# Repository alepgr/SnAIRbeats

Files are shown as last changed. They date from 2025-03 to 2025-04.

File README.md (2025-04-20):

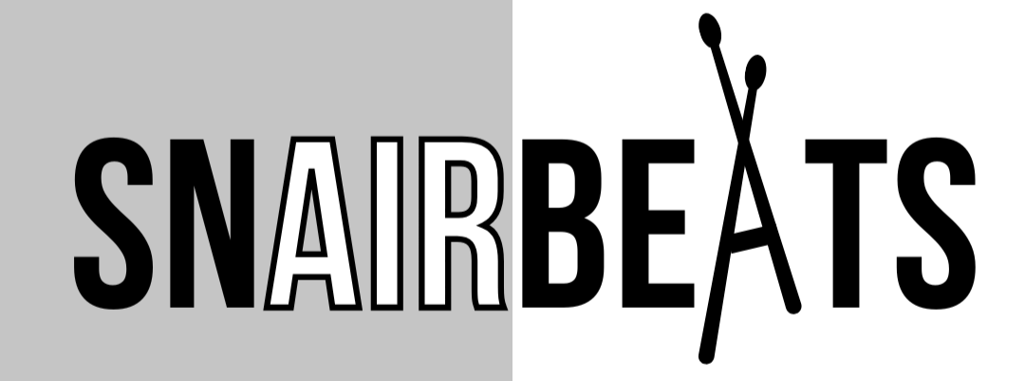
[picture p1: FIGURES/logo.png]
Snairbeats logo


# SnAIRbeats
SnAirBeats is a next generation method to practice the drums, while reducing noise and space typically required to do so. The SnAirBeat set uses intertial measurement units (IMU) within the sticks to track their movement and play a corresponding drum, not requiring any physical hitting like modern electric drum sets need.

# Building
SnAIRBeats requires the following components to work:

* 1x  [Raspberry Pi 5](https://uk.rs-online.com/web/p/raspberry-pi/0219255)
* 2x  [SEN15335 Breakout IMU](https://uk.rs-online.com/web/p/sensor-development-tools/2836590)
* 1x  [External USB Speaker](https://thepihut.com/products/mini-external-usb-stereo-speaker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)

The circuit's wires should be at least 1m long to ensure comfortable movement while playing to avoid risk of damaging the project.
A wiring guide can be seen below:

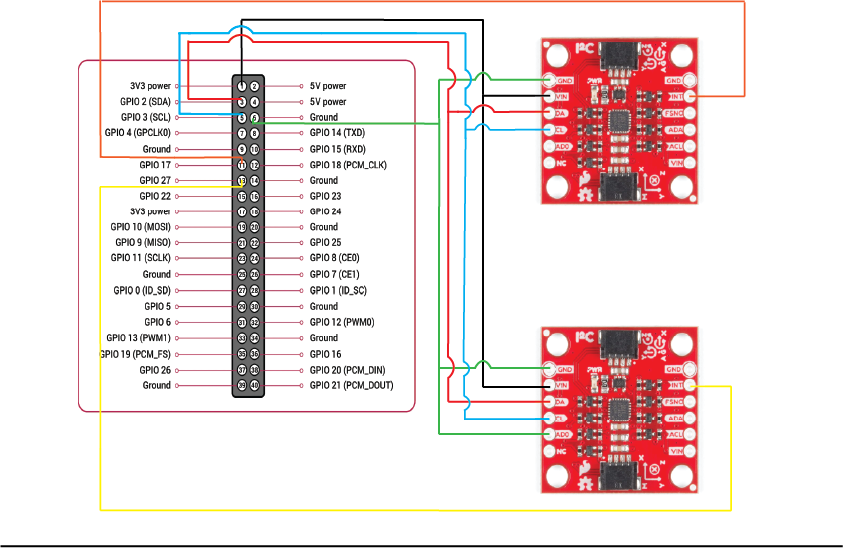
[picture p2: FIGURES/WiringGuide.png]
Wiring guide


The drumsticks for the project need to be 3D printed via the [STLs](/STLs/) provided within this repository.

# Prerequisites
Firstly it should be noted that SnAIRBeats can only run on a Linux system. It is recommened to use a Raspberry Pi operating system such as [Raspebian](https://www.raspberrypi.com/software/) as the packages will not work on Windows systems.  

Before installing any of the prerequisites, please update your package list with:
```
sudo apt update
```

There are 4 main libraries that need to be installed for this project:
* Libgpiod - for general purpose input/output
* mraa - IoT and hardware interface library (required for IMU driver)
* YAML - Support for YAML (required for IMU driver)
* ALSA - To process and play sound files

These packages can be installed by running the following commands through the terminal of the Raspberry Pi.
```
sudo apt install -y libgpiod-dev
sudo apt install -y libmraa-dev
sudo apt install -y libyaml-dev
sudo apt install -y libasound2-dev
```

# Compliation from source

The project is built using a series of CMakeLists.txt which locate and link the required internal and external libraries for the project. By running the code below, the CMake will generate the respective make files within each of files. Running make will build the project and return an executable.

```
cmake .
make
```

It may take a few seconds for everything to build properly, but once everything has been successfully created you can use the code below to run SnAIRBeats.  

```
./SnairBeats
```

# Usage
SnAIRBeats works by reading the direction of acceleration within the IMUs. Holding the sticks with the X-direction representing the vertical axis:
* Hitting a stick down will play a snare drum
* Hitting a stick to either side will play a high tom
* Lunging the stick forward will play a crash cymbal

If desired, the sounds played by each direction can be changed by swapping files in the ALSAPlayer library found either [here](src/libs/ALSAPlayer/include) or through the command directory:
```
cd src/libs/ALSAPlayer/include
ls
```

## Maximum Latency
The highest sampling rate the SEN 15335 IMUs can work at is 1.125kHz.  
This value can be adjusted in the main.cpp file by altering the SampleRateDivider variable. This divides the sampling rate by 1+SampleRateDivider.  

We have found that the maximum latency the sticks can be reliably played at is 25Hz (1125Hz/44+1). While decreasing the latency may improve the sensitivity of the sticks, the higher this value is the greater the power consumption will be.

# Libraries
Here is a small description of each of the libraries used within the project and what they are used for.

## ALSAPlayer
ALSAPlayer takes .wav files from inside its [include folder](src/libs/ALSAPlayer/include/) and converts them into audio buffers using the ConvertFiles function. This library is heavily based off of driver written by [Adam Stark](https://github.com/adamstark) found at [https://github.com/adamstark/AudioFile](https://github.com/adamstark/AudioFile).

Audio devices are opened using the Open function which once finished can be used to play the created audiobuffers using the playFile function. The playFile function is built to play small audios and will interrupt itself, cancelling whatever is playing to play the next audio. This is much easier for SnAIRBeats compared to mixing as the interrupt of the drum notes is not noticable to the human ear, especially with the sample delay between each hit.

## GPIO
The GPIO library initialises the GPIO pins of the Raspberry Pi. Using [libgpiod](https://libgpiod.readthedocs.io/en/latest/), an event driven interrupt function called "worker" is used to read one of the GPIO pins for a HIGH value. The function is blocked until a rising edge event is seen in the GPIO pin selected in the constructor.  

The interrupt is data-ready based and therefore wakes whenever new data is available from the sensor. Within the constructor, 2 objects were passed in, the Maths object and the I2C-IMU driver. The new data is read from the IMU's registers using a read function and passed into a callback which inputs the data into the maths object to be thresholded.

## I2C
The I2C library is a driver written specifically for the [ICM-20948 chip](https://invensense.tdk.com/wp-content/uploads/2016/06/DS-000189-ICM-20948-v1.3.pdf) seen within the SEN 15335 IMU and is very heavily based off of driver written by [NTKot](https://github.com/NTkot) found at [https://github.com/NTkot/icm20948_i2c](https://github.com/NTkot/icm20948_i2c) with the Raw-Data-Ready interrupt turned on and the magnetometer turned off.

For each sensor used within the system, an object from this driver is built with a separate I2C address to differentiate between the two. These objects come with pre-built functions, must useful is the Read_Accel_Gyro which reads the registers of the IMU and stores the values in a variable within the object. These variables are what are passed into the IMUMaths callback through the GPIO worker whenever data is ready.

## IMUMaths
This libary was written to threshold the data that came through from the GPIO worker and has two main goals. Firstly it reads the data passed through and checks whether any of the values correlate to a hit and then play the corresponding audio from the ALSAAudio object. It also contains a sample delay to stop multiple sounds being played from the same hit. This is achieved using a simple boolean that is turned true after a hit is detected and waits a set number of samples before the boolean flips back, allowing another hit to be detected.

# Unit tests
This project uses unit testing to validate the functionality of the key classes, including classes responsible for IMU data processing and audio playback.

Tests are written using the GoogleTest framework and integrated with CTest for easy execution.

To run the tests from the root directory, use:
```
./run_tests
```
or to use CMake directly, run:
```
ctest
```

# Documentation
Complete documentation for this project can be found in [documentation.pdf](./documentation.pdf).

# Sponsorship and funding
We are extremely grateful for RS Components for providing us with components that allowed us to complete this project. We are also very grateful to the ENG5220 Real Time Embedded Programming lecturers and teaching assistants for their guidance throughout the past three months.

# Media
* [Instagram](https://www.instagram.com/snairbeats/)

# Authors
* Calum Robertson
* Aleksandar Zahariev
* Mohammed Alqabandi
* Renata Cia Sanches Loberto
* Alejandra Paja Garcia

# Licenses
The IMU driver has been adapted from the driver written by [NTKot](https://github.com/NTkot) and can be found at [https://github.com/NTkot/icm20948_i2c](https://github.com/NTkot/icm20948_i2c)

The ALSAPlayer library has been adapted from the driver written by [Adam Stark](https://github.com/adamstark) and can be found at [https://github.com/adamstark/AudioFile](https://github.com/adamstark/AudioFile)

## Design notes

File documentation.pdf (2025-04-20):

## SnAirBeats

1.0

Generated by Doxygen 1.13.2

i

1 SnAirBeats | 1
2 Namespace Index | 5
3 Hierarchical Index | 7
4 Class Index | 9
5 File Index | 11
6 Namespace Documentation | 13
7 Class Documentation | 15

Generated by Doxygen

ii

iii

iv

8 File Documentation | 43

# Chapter 1

# SnAirBeats

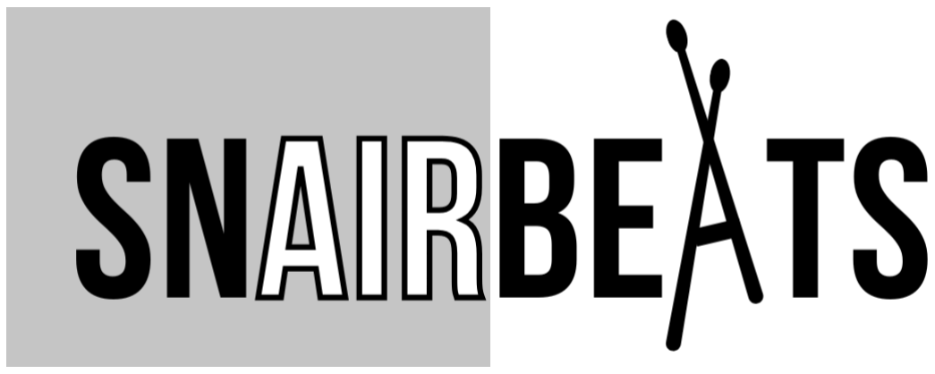
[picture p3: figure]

## 1.1 SnAIRbeats

SnAirBeats is a next generation method to practice the drums, while reducing noise and space typically required to do so. The SnAirBeat set uses intertial measurement units (IMU) within the sticks to track their movement and play a corresponding drum, not requiring any physical hitting like modern electric drum sets need.

## 1.2 Building

SnAIRBeats requires the following components to work:

- 1x Raspberry Pi 5 (https://uk.rs-online.com/web/p/raspberry-pi/0219255)
- 2x SEN15335 Breakout IMU (https://uk.rs-online.com/web/p/sensor-development-tools/2836590)
- 1x External USB Speaker (https://thepihut.com/products/mini-external-usb-stereo-speaker?variant=31955934801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)

The circuit's wires should be at least 1m long to ensure comfortable movement while playing to avoid risk of dam-aging the project. A wiring guide can be seen below:

### 2 SnAirBeats

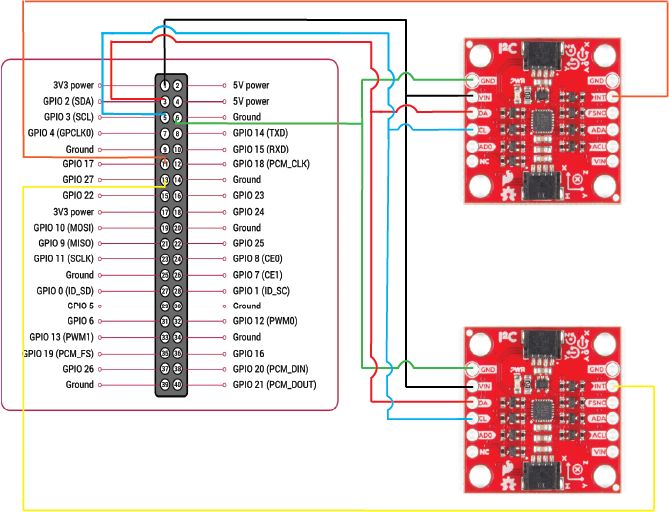
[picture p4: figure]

The drumsticks for the project need to be 3D printed via the STLs provided within this repository.

## 1.3 Prerequisites

Firstly it should be noted that SnAIRBeats can only run on a Linux system. It is recommened to use a Raspberry Pi operating system such as Raspebian (https://www.raspberrypi.com/software/) as the packages will not work on Windows systems.

Before installing any of the prerequisites, please update your package list with:

sudo apt update

There are 4 main libraries that need to be installed for this project:

- Libgpiod - for general purpose input/output
- mraa - IoT and hardware interface library (required for IMU driver)
- YAML - Support for YAML (required for IMU driver)
- ALSA - To process and play sound files

These packages can be installed by running the following commands through the terminal of the Raspberry Pi.

sudo apt install -y libgpiod-dev
sudo apt install -y libmraa-dev
sudo apt install -y libyaml-dev sudo apt install -y libasound2-dev

## 1.4 Compliation from source

The project is built using a series of CMakeLists.txt which locate and link the required internal and external libraries for the project. By running the code below, the CMake will generate the respective make files within each of files. Running make will build the project and return an executable.

cmake .
make

It may take a few seconds for everything to build properly, but once everything has been successfully created you can use the code below to run SnAIRBeats.

./SnairBeats

1.5 Usage | 3

## 1.5 Usage

SnAIRBeats works by reading the direction of acceleration within the IMUs. Holding the sticks with the X-direction representing the vertical axis:

- Hitting a stick down will play a snare drum
- Hitting a stick to either side will play a high tom
- Lunging the stick forward will play a crash cymbal

If desired, the sounds played by each direction can be changed by swapping files in the ALSAPlayer library found either here or through the command directory:

cd src/libs/ALSAPlayer/include
ls

### 1.5.1 Maximum Latency

The highest sampling rate the SEN 15335 IMUs can work at is 1.125kHz.
This value can be adjusted in the main.cpp file by altering the SampleRateDivider variable. This divides the sampling rate by 1+SampleRateDivider.

We have found that the maximum latency the sticks can be reliably played at is 25Hz (1125Hz/44+1). While decreas-ing the latency may improve the sensitivity of the sticks, the higher this value is the greater the power consumption will be.

## 1.6 Libraries

Here is a small description of each of the libraries used within the project and what they are used for.

### 1.6.1 ALSAPlayer

ALSAPlayer takes .wav files from inside its include folder and converts them into audio buffers using the ConvertFiles function. This library is heavily based off of driver written by Adam Stark (https://github.com/adamstark) found at https←-://github.com/adamstark/AudioFile.

Audio devices are opened using the Open function which once finished can be used to play the created audiobuffers using the playFile function. The playFile function is built to play small audios and will interrupt itself, cancelling whatever is playing to play the next audio. This is much easier for SnAIRBeats compared to mixing as the interrupt of the drum notes is not noticable to the human ear, especially with the sample delay between each hit.

### 1.6.2 GPIO

The GPIO library initialises the GPIO pins of the Raspberry Pi. Using libgpiod, (https://libgpiod.readthedocs.io/en/latest/) an event driven interrupt function called "worker" is used to read one of the GPIO pins for a HIGH value. The function is blocked until a rising edge event is seen in the GPIO pin selected in the constructor.

The interrupt is data-ready based and therefore wakes whenever new data is available from the sensor. Within the constructor, 2 objects were passed in, the Maths object and the I2C-IMU driver. The new data is read from the IMU's registers using a read function and passed into a callback which inputs the data into the maths object to be thresholded.

### 4 SnAirBeats

### 1.6.3 I2C

The I2C library is a driver written specifically for the ICM-20948 chip (https://invensense.tdk.com/wp-content/uploads/2016/06/DS-000189-ICM-20948-v1.3.pdf) seen within the SEN 15335 IMU and is very heavily based off of driver written by NTKot found at https://github.com/NTkot/icm20948←-_i2c (https://github.com/NTkot/icm20948_i2c) with the Raw-Data-Ready interrupt turned on and the magnetometer turned off.

For each sensor used within the system, an object from this driver is built with a separate I2C address to differentiate between the two. These objects come with pre-built functions, must useful is the Read_Accel_Gyro which reads the registers of the IMU and stores the values in a variable within the object. These variables are what are passed into the IMUMaths callback through the GPIO worker whenever data is ready.

### 1.6.4 IMUMaths

This libary was written to threshold the data that came through from the GPIO worker and has two main goals. Firstly it reads the data passed through and checks whether any of the values correlate to a hit and then play the corresponding audio from the ALSAAudio object. It also contains a sample delay to stop multiple sounds being played from the same hit. This is achieved using a simple boolean that is turned true after a hit is detected and waits a set number of samples before the boolean flips back, allowing another hit to be detected.

## 1.7 Unit tests

This project uses unit testing to validate the functionality of the key classes, including classes responsible for IMU data processing and audio playback.

Tests are written using the GoogleTest framework and integrated with CTest for easy execution.

To run the tests from the root directory, use:

./run_tests

or to use CMake directly, run:

ctest

## 1.8 Documentation

Complete documentation for this project can be found in documentation.pdf.

## 1.9 Sponsorship and funding

We are very grateful for RS Components for providing us with components that allowed us to complete this project.

## 1.10 Media

- Instagram (https://www.instagram.com/snairbeats/)

1.11 Authors | 5

## 1.11 Authors

- Calum Robertson
- Aleksandar Zahariev
- Mohammed Alqabandi
- Renata Cia Sanches Loberto
- Alejandra Paja Garcia

## 1.12 Licenses

The IMU driver has been adapted from the driver written by NTKot (https://github.com/NTkot) and can be found at https://github.←-com/NTkot/icm20948_i2c (https://github.com/NTkot/icm20948_i2c)

The ALSAPlayer library has been adapted from the driver written by Adam Stark (https://github.com/adamstark) and can be found at https://github.com/adamstark/AudioFile

### 6 SnAirBeats

# Chapter 2

# Namespace Index

## 2.1 Namespace List

Here is a list of all namespaces with brief descriptions:

AudioPlayerName | | 13
GPIOName | | 13
icm20948 | | 13
IMUMathsName | | 13

### 8 Namespace Index

# Chapter 3

# Hierarchical Index

## 3.1 Class Hierarchy

This inheritance list is sorted roughly, but not completely, alphabetically:

AudioPlayerName::AudioPlayer::ActiveSound | | 15
AudioPlayerName::AudioPlayer | | 18
GPIOName::GPIOClass::Callback | | 25
GPIOName::MathsCallbackStruct | 40
IMUMathsName::IMUMaths::Callback | 27
IMUMathsName::AudioCallback | 16
GPIOName::GPIOClass | | 28
icm20948::ICM20948_I2C | | 32
IMUMathsName::IMUMaths | | 38

### 10 Hierarchical Index

# Chapter 4

# Class Index

## 4.1 Class List

Here are the classes, structs, unions and interfaces with brief descriptions:

GPIOName::GPIOClass::Callback

IMUMathsName::IMUMaths::Callback

### 12 Class Index

# Chapter 5

# File Index

## 5.1 File List

Here is a list of all files with brief descriptions:

### 14 File Index

# Chapter 6

# Namespace Documentation

## 6.1 AudioPlayerName Namespace Reference

Classes

- class AudioPlayer

## 6.2 GPIOName Namespace Reference

Classes

- class GPIOClass
- struct MathsCallbackStruct

## 6.3 icm20948 Namespace Reference

Classes

- class ICM20948_I2C

## 6.4 IMUMathsName Namespace Reference

Classes

- struct AudioCallback
- class IMUMaths

### 16 Namespace Documentation

# Chapter 7

# Class Documentation

## 7.1 AudioPlayerName::AudioPlayer::ActiveSound Struct Reference

Collaboration diagram for AudioPlayerName::AudioPlayer::ActiveSound:

### AudioPlayerName::AudioPlayer ::ActiveSound

+ | buffer
+ | position

Public Attributes

- std::vector< int32_t > ∗ buffer
- size_t position

### 7.1.1 Member Data Documentation

### 7.1.1.1 buffer

std::vector<int32_t>∗ AudioPlayerName::AudioPlayer::ActiveSound::buffer

### 7.1.1.2 position

size_t AudioPlayerName::AudioPlayer::ActiveSound::position

The documentation for this struct was generated from the following file:

- src/libs/ALSAPlayer/include/ALSAPlayer.hpp

### 18 Class Documentation

## 7.2 IMUMathsName::AudioCallback Struct Reference

#include <IMUMaths.hpp>

Inheritance diagram for IMUMathsName::AudioCallback:

### IMUMathsName::AudioCallback

+ | Audio
+ | AudioCallback()
+ | AudioTrigger()

### IMUMathsName::IMUMaths ::Callback

+ | AudioTrigger()
+ | ~Callback()

7.2 IMUMathsName::AudioCallback Struct Reference | 19

Collaboration diagram for IMUMathsName::AudioCallback:

### IMUMathsName::AudioCallback

+ | AudioCallback()
+ | AudioTrigger()

### IMUMathsName::IMUMaths ::Callback

+ | AudioTrigger()
+ | ~Callback()

### AudioPlayerName::AudioPlayer

+ | fileBuffers
+ | StopMixingThread

### - deviceName - sampleRate - channels - format

| and 5 more...
+ | AudioPlayer()
+ | open()
+ | startMixer()
+ | stopMixer()
| and 3 more...

### - mixerThreadLoop() - ConvertFiles()

### +Audio

Public Member Functions

- AudioCallback (AudioPlayerName::AudioPlayer &audio)
- virtual void AudioTrigger (const std::string &FilePath)

Public Member Functions inherited from IMUMathsName::IMUMaths::Callback

- virtual ∼Callback ()

Public Attributes

- AudioPlayerName::AudioPlayer & Audio

### 20 Class Documentation

### 7.2.1 Constructor & Destructor Documentation

### 7.2.1.1 AudioCallback()

IMUMathsName::AudioCallback::AudioCallback (

AudioPlayerName::AudioPlayer & audio) [inline]

### 7.2.2 Member Function Documentation

### 7.2.2.1 AudioTrigger()

virtual void IMUMathsName::AudioCallback::AudioTrigger (

const std::string & FilePath) [inline], [virtual]

Implements IMUMathsName::IMUMaths::Callback.

### 7.2.3 Member Data Documentation

### 7.2.3.1 Audio

AudioPlayerName::AudioPlayer& IMUMathsName::AudioCallback::Audio

The documentation for this struct was generated from the following file:

- src/libs/IMUMaths/include/IMUMaths.hpp

## 7.3 AudioPlayerName::AudioPlayer Class Reference

#include <ALSAPlayer.hpp>

7.3 AudioPlayerName::AudioPlayer Class Reference | 21

Collaboration diagram for AudioPlayerName::AudioPlayer:

### AudioPlayerName::AudioPlayer

+ | fileBuffers
+ | StopMixingThread

### - deviceName - sampleRate - channels - format

| and 5 more...
+ | AudioPlayer()
+ | open()
+ | startMixer()
+ | stopMixer()
| and 3 more...

### - mixerThreadLoop() - ConvertFiles()

Classes

- struct ActiveSound

Public Member Functions

- AudioPlayer (const std::string &device="default", unsigned int rate=44100, unsigned int ch=2, snd_pcm_←-format_t fmt=SND_PCM_FORMAT_S16_LE, snd_pcm_uframes_t frames=256, const std::vector< std::string > &filesToConvert={"src/libs/ALSAPlayer/include/CrashCymbal.wav", "src/libs/ALSAPlayer/include/High←-Tom.wav", "src/libs/ALSAPlayer/include/SnareDrum.wav"})

Constructor for AudioPlayer class.
- bool open ()

Open PCM device for playback.
- bool startMixer ()

Start mixer thread.
- void stopMixer ()

Stop mixer thread, closes thread when called.
- bool addSoundToMixer (const std::string &fileKey)

Add input sound to mixer and play it.
- void close ()

Close PCM handle and free all associated resources.
- ∼AudioPlayer ()

Destructor.

### 22 Class Documentation

Public Attributes

- std::unordered_map< std::string, std::vector< int32_t > > fileBuffers
- bool StopMixingThread = false

Private Member Functions

- void mixerThreadLoop ()
- void ConvertFiles (const std::vector< std::string > &filePaths)

Private Attributes

- std::string deviceName
- unsigned int sampleRate
- unsigned int channels
- snd_pcm_format_t format
- snd_pcm_uframes_t framesPerPeriod
- snd_pcm_t ∗ handle
- std::thread mixThread
- std::vector< ActiveSound > ActiveSounds
- std::mutex ActiveMutex

### 7.3.1 Constructor & Destructor Documentation

### 7.3.1.1 AudioPlayer()

AudioPlayerName::AudioPlayer::AudioPlayer (

const std::string & device = "default",

unsigned int rate = 44100,

unsigned int ch = 2,

snd_pcm_format_t fmt = SND_PCM_FORMAT_S16_LE,

snd_pcm_uframes_t frames = 256,

const std::vector< std::string > & filesToConvert = {"src/libs/ALSAPlayer/include/CrashCymbal.wav", "src/libs/ALSAPlayer/include/HighTom.wav", "src/libs/ALSAPlayer/include/SnareDrum.wav"})

[inline]

Constructor for AudioPlayer class.

Handles audio file loading, conversion and playback.

Parameters

device | The name of the ALSA device to use.
rate | Sample rate in Hz.
ch | Number of channels.
fmt | Format of audio data.
frames | Number of frames per period.
filesToConvert | Sound files used.

7.3 AudioPlayerName::AudioPlayer Class Reference | 23

7.3.1.2 ∼AudioPlayer()

AudioPlayerName::AudioPlayer::∼AudioPlayer () [inline]

Destructor.

Here is the call graph for this function:

AudioPlayerName::AudioPlayer ::~AudioPlayer

AudioPlayerName::AudioPlayer ::close

AudioPlayerName::AudioPlayer ::stopMixer

### 7.3.2 Member Function Documentation

### 7.3.2.1 addSoundToMixer()

bool AudioPlayerName::AudioPlayer::addSoundToMixer (

const std::string & fileKey) [inline]

Add input sound to mixer and play it.

It includes the following steps:

- register detected sound in the mixer
- add sound to buffer and remove sounds that have finished playing
- play sound

Parameters

fileKey Sound file key.

Returns

Returns true if sound was added to mixer, false if error

### 24 Class Documentation

### 7.3.2.2 close()

void AudioPlayerName::AudioPlayer::close () [inline]

Close PCM handle and free all associated resources.

Here is the call graph for this function:

AudioPlayerName::AudioPlayer ::close

AudioPlayerName::AudioPlayer ::stopMixer

Here is the caller graph for this function:

AudioPlayerName::AudioPlayer ::close

AudioPlayerName::AudioPlayer ::~AudioPlayer

### 7.3.2.3 ConvertFiles()

void AudioPlayerName::AudioPlayer::ConvertFiles (

const std::vector< std::string > & filePaths) [inline], [private]

### 7.3.2.4 mixerThreadLoop()

void AudioPlayerName::AudioPlayer::mixerThreadLoop () [inline], [private]

Here is the caller graph for this function:

AudioPlayerName::AudioPlayer ::mixerThreadLoop

AudioPlayerName::AudioPlayer
::startMixer | Generated by Doxygen

7.3 AudioPlayerName::AudioPlayer Class Reference | 25

### 7.3.2.5 open()

bool AudioPlayerName::AudioPlayer::open () [inline]

Open PCM device for playback.

It includes the following steps:

- open the PCM device
- allocate hardware parameters object and fill it in with default values
- set desired hardware parameters (set access type, format, number of channels, sample rate, period size)
- write parameters to the driver
- get period size

Returns

Returns true is open was successful, but false if something went wrong

### 7.3.2.6 startMixer()

bool AudioPlayerName::AudioPlayer::startMixer () [inline]

Start mixer thread.

Ensures that a handle exists before opening the mixing thread and tells the user to open the device of not. Sets a boolean to false to control the thread and starts the mixer

Returns

Returns true if mixer thread started correctly, false if error

Here is the call graph for this function:

AudioPlayerName::AudioPlayer ::startMixer

AudioPlayerName::AudioPlayer
::mixerThreadLoop Generated by Doxygen

### 26 Class Documentation

### 7.3.2.7 stopMixer()

void AudioPlayerName::AudioPlayer::stopMixer () [inline]

Stop mixer thread, closes thread when called.

Here is the caller graph for this function:

AudioPlayerName::AudioPlayer ::stopMixer

AudioPlayerName::AudioPlayer ::close

AudioPlayerName::AudioPlayer ::~AudioPlayer

### 7.3.3 Member Data Documentation

### 7.3.3.1 ActiveMutex

std::mutex AudioPlayerName::AudioPlayer::ActiveMutex [private]

### 7.3.3.2 ActiveSounds

std::vector<ActiveSound> AudioPlayerName::AudioPlayer::ActiveSounds [private]

### 7.3.3.3 channels

unsigned int AudioPlayerName::AudioPlayer::channels [private]

### 7.3.3.4 deviceName

std::string AudioPlayerName::AudioPlayer::deviceName [private]

### 7.3.3.5 fileBuffers

std::unordered_map<std::string, std::vector<int32_t> > AudioPlayerName::AudioPlayer::file←-

Buffers

### 7.3.3.6 format

snd_pcm_format_t AudioPlayerName::AudioPlayer::format [private]

### 7.3.3.7 framesPerPeriod

snd_pcm_uframes_t AudioPlayerName::AudioPlayer::framesPerPeriod [private]

7.4 GPIOName::GPIOClass::Callback Struct Reference | 27

### 7.3.3.8 handle

snd_pcm_t∗ AudioPlayerName::AudioPlayer::handle [private]

### 7.3.3.9 mixThread

std::thread AudioPlayerName::AudioPlayer::mixThread [private]

### 7.3.3.10 sampleRate

unsigned int AudioPlayerName::AudioPlayer::sampleRate [private]

### 7.3.3.11 StopMixingThread

bool AudioPlayerName::AudioPlayer::StopMixingThread = false

The documentation for this class was generated from the following file:

- src/libs/ALSAPlayer/include/ALSAPlayer.hpp

## 7.4 GPIOName::GPIOClass::Callback Struct Reference

Empty callback to later be filled. Includes destructor.

#include <gpioevent.h>

Inheritance diagram for GPIOName::GPIOClass::Callback:

### GPIOName::GPIOClass ::Callback

### + MathsCallback() + ~Callback()

### GPIOName::MathsCallbackStruct

+ | Maths
+ | MathsCallbackStruct()
+ | MathsCallback() Generated by Doxygen

### 28 Class Documentation

Collaboration diagram for GPIOName::GPIOClass::Callback:

### GPIOName::GPIOClass ::Callback

### + MathsCallback() + ~Callback()

Public Member Functions

- virtual void MathsCallback (float X, float Y, float Z)=0
- virtual ∼Callback ()

### 7.4.1 Detailed Description

Empty callback to later be filled. Includes destructor.

### 7.4.2 Constructor & Destructor Documentation

7.4.2.1 ∼Callback()

virtual GPIOName::GPIOClass::Callback::∼Callback () [inline], [virtual]

### 7.4.3 Member Function Documentation

### 7.4.3.1 MathsCallback()

virtual void GPIOName::GPIOClass::Callback::MathsCallback (

float X,

float Y,

float Z) [pure virtual]

Implemented in GPIOName::MathsCallbackStruct.

The documentation for this struct was generated from the following file:

- src/libs/GPIO/include/gpioevent.h

7.5 IMUMathsName::IMUMaths::Callback Struct Reference | 29

## 7.5 IMUMathsName::IMUMaths::Callback Struct Reference

Empty callback to later be filled. Includes destructor.

#include <IMUMaths.hpp>

Inheritance diagram for IMUMathsName::IMUMaths::Callback:

### IMUMathsName::IMUMaths ::Callback

+ | AudioTrigger()
+ | ~Callback()

### IMUMathsName::AudioCallback

+ | Audio
+ | AudioCallback()
+ | AudioTrigger()

Collaboration diagram for IMUMathsName::IMUMaths::Callback:

### IMUMathsName::IMUMaths ::Callback

+ | AudioTrigger()
+ | ~Callback()

Public Member Functions

- virtual void AudioTrigger (const std::string &FilePath)=0
- virtual ∼Callback ()

### 30 Class Documentation

### 7.5.1 Detailed Description

Empty callback to later be filled. Includes destructor.

### 7.5.2 Constructor & Destructor Documentation

7.5.2.1 ∼Callback()

virtual IMUMathsName::IMUMaths::Callback::∼Callback () [inline], [virtual]

### 7.5.3 Member Function Documentation

### 7.5.3.1 AudioTrigger()

virtual void IMUMathsName::IMUMaths::Callback::AudioTrigger (

const std::string & FilePath) [pure virtual]

Implemented in IMUMathsName::AudioCallback.

The documentation for this struct was generated from the following file:

- src/libs/IMUMaths/include/IMUMaths.hpp

## 7.6 GPIOName::GPIOClass Class Reference

#include <gpioevent.h>

7.6 GPIOName::GPIOClass Class Reference | 31

Collaboration diagram for GPIOName::GPIOClass:

GPIOName::GPIOClass
- chip
- SensorLine
- InterruptPin
- Counter
- Pause
- running
+ GPIOClass()
+ Worker()
+ GPIOStop()
+ RegisterCallback()

icm20948::ICM20948_I2C
+ accel
+ gyro
+ magn
+ settings
- _i2c
- _i2c_bus
- _i2c_address
- _current_bank
and 3 more...
+ ICM20948_I2C()
+ enable_DRDY_INT()
+ check_DRDY_INT()
- _write_byte()
- _read_byte()
- _write_bit()
- _read_bit()
and 15 more...

-sensor

GPIOName::GPIOClass
::Callback

+ MathsCallback()
+ ~Callback()

-callback

Classes

- struct Callback

Empty callback to later be filled. Includes destructor.

Public Member Functions

- GPIOClass (const char ∗chipName, int InterruptPin, icm20948::ICM20948_I2C &sensor)

### 32 Class Documentation

Constructor for GPIOClass.
- void Worker ()

Event driven worker reading data when HIGH seen on GPIO.
- void GPIOStop ()

Changes a boolean to end the worker.
- void RegisterCallback (Callback ∗cb)

Registers a callback.

Private Attributes

- gpiod_chip ∗ chip
- gpiod_line ∗ SensorLine
- int InterruptPin
- int Counter
- bool Pause = true
- icm20948::ICM20948_I2C & sensor
- std::atomic< bool > running {true}
- Callback ∗ callback = nullptr

### 7.6.1 Constructor & Destructor Documentation

### 7.6.1.1 GPIOClass()

GPIOName::GPIOClass::GPIOClass (

const char ∗ chipName,

int InterruptPin,

icm20948::ICM20948_I2C & sensor)

Constructor for GPIOClass.

Parameters

chipName | The name of the GPIO chip (e.g., "gpiochip0")
InterruptPin | The GPIO pin number for interrupts
sensor | access to ICM20948_I2C objects

See also

icm20948::ICM20948_I2C

### 7.6.2 Member Function Documentation

### 7.6.2.1 GPIOStop()

void GPIOName::GPIOClass::GPIOStop ()

Changes a boolean to end the worker.

### 7.6.2.2 RegisterCallback()

void GPIOName::GPIOClass::RegisterCallback (

Callback ∗ cb) [inline]

Registers a callback.

Overwrites the virtual void function within the class with a function taken in via this function

7.6 GPIOName::GPIOClass Class Reference | 33

Parameters

cb callback to register

### 7.6.2.3 Worker()

void GPIOName::GPIOClass::Worker ()

Event driven worker reading data when HIGH seen on GPIO.

This function is an event driven interrupt controlled by a GPIO pin. Once this GPIO pin reads HIGH the function will read the data registers using the ReadAccel() callback from the IMU's driver which is then fed into the IMU Maths object to be analysed.

### 7.6.3 Member Data Documentation

### 7.6.3.1 callback

Callback∗ GPIOName::GPIOClass::callback = nullptr [private]

### 7.6.3.2 chip

gpiod_chip∗ GPIOName::GPIOClass::chip [private]

### 7.6.3.3 Counter

int GPIOName::GPIOClass::Counter [private]

### 7.6.3.4 InterruptPin

int GPIOName::GPIOClass::InterruptPin [private]

### 7.6.3.5 Pause

bool GPIOName::GPIOClass::Pause = true [private]

### 7.6.3.6 running

std::atomic<bool> GPIOName::GPIOClass::running {true} [private]

### 7.6.3.7 sensor

icm20948::ICM20948_I2C& GPIOName::GPIOClass::sensor [private]

### 34 Class Documentation

### 7.6.3.8 SensorLine

gpiod_line∗ GPIOName::GPIOClass::SensorLine [private]

The documentation for this class was generated from the following file:

- src/libs/GPIO/include/gpioevent.h

## 7.7 icm20948::ICM20948_I2C Class Reference

#include <icm20948_i2c.hpp>

Collaboration diagram for icm20948::ICM20948_I2C:

### icm20948::ICM20948_I2C + accel + gyro + magn + settings - _i2c - _i2c_bus - _i2c_address - _current_bank

and 3 more...

### + ICM20948_I2C() + enable_DRDY_INT() + check_DRDY_INT() - _write_byte() - _read_byte() - _write_bit() - _read_bit()

and 15 more...

Public Member Functions

- ICM20948_I2C (unsigned i2c_bus, unsigned i2c_address=ICM20948_I2C_ADDR, icm20948::settings=icm20948←-::settings())

Constructor for ICM20948_I2C class.
- bool enable_DRDY_INT ()

Enables the Data Ready Interrupt.
- bool check_DRDY_INT ()

Checks if the Data Ready Interrupt is active.

7.7 icm20948::ICM20948_I2C Class Reference | 35

Public Attributes

- float accel [3]
- float gyro [3]
- float magn [3]
- icm20948::settings settings

Private Member Functions

- bool _write_byte (const uint8_t bank, const uint8_t reg, const uint8_t byte)
- bool _read_byte (const uint8_t bank, const uint8_t reg, uint8_t &byte)
- bool _write_bit (const uint8_t bank, const uint8_t reg, const uint8_t bit_pos, const bool bit)
- bool _read_bit (const uint8_t bank, const uint8_t reg, const uint8_t bit_pos, bool &bit)
- bool _read_block_bytes (const uint8_t bank, const uint8_t start_reg, uint8_t ∗bytes, const int length)
- bool _write_mag_byte (const uint8_t mag_reg, const uint8_t byte)
- bool _read_mag_byte (const uint8_t mag_reg, uint8_t &byte)
- bool _read_int_byte (const uint8_t bank, const uint8_t reg, uint8_t &byte)
- bool _set_bank (uint8_t bank)
- bool _set_accel_sample_rate_div ()
- bool _set_accel_range_dlpf ()
- bool _set_gyro_sample_rate_div ()
- bool _set_gyro_range_dlpf ()
- bool _magnetometer_init ()
- bool _magnetometer_enable ()
- bool _magnetometer_set_mode ()
- bool _magnetometer_configured ()
- bool _magnetometer_set_readout ()
- bool _chip_i2c_master_reset ()

Private Attributes

- mraa::I2c _i2c
- unsigned _i2c_bus
- unsigned _i2c_address
- uint8_t _current_bank
- float _accel_scale_factor
- float _gyro_scale_factor
- float _magn_scale_factor

### 7.7.1 Constructor & Destructor Documentation

### 7.7.1.1 ICM20948_I2C()

icm20948::ICM20948_I2C::ICM20948_I2C (

unsigned i2c_bus,

unsigned i2c_address = ICM20948_I2C_ADDR,

icm20948::settings = icm20948::settings())

Constructor for ICM20948_I2C class.

### 36 Class Documentation

Parameters

i2c_bus | The I2C bus number to which the sensor is connected.
i2c_address | The I2C address of the sensor (default is ICM20948_I2C_ADDR).
settings | The settings structure containing configuration parameters for the sensor. If not provided, default settings will be used

See also

icm20948::settings (external).

### 7.7.2 Member Function Documentation

### 7.7.2.1 _chip_i2c_master_reset()

bool icm20948::ICM20948_I2C::_chip_i2c_master_reset () [private]

### 7.7.2.2 _magnetometer_configured()

bool icm20948::ICM20948_I2C::_magnetometer_configured () [private]

### 7.7.2.3 _magnetometer_enable()

bool icm20948::ICM20948_I2C::_magnetometer_enable () [private]

### 7.7.2.4 _magnetometer_init()

bool icm20948::ICM20948_I2C::_magnetometer_init () [private]

### 7.7.2.5 _magnetometer_set_mode()

bool icm20948::ICM20948_I2C::_magnetometer_set_mode () [private]

### 7.7.2.6 _magnetometer_set_readout()

bool icm20948::ICM20948_I2C::_magnetometer_set_readout () [private]

### 7.7.2.7 _read_bit()

bool icm20948::ICM20948_I2C::_read_bit (

const uint8_t bank,

const uint8_t reg,

const uint8_t bit_pos,

bool & bit) [private]

7.7 icm20948::ICM20948_I2C Class Reference | 37

### 7.7.2.8 _read_block_bytes()

bool icm20948::ICM20948_I2C::_read_block_bytes (

const uint8_t bank,

const uint8_t start_reg,

uint8_t ∗ bytes,

const int length) [private]

### 7.7.2.9 _read_byte()

bool icm20948::ICM20948_I2C::_read_byte (

const uint8_t bank,

const uint8_t reg,

uint8_t & byte) [private]

### 7.7.2.10 _read_int_byte()

bool icm20948::ICM20948_I2C::_read_int_byte (

const uint8_t bank,

const uint8_t reg,

uint8_t & byte) [private]

### 7.7.2.11 _read_mag_byte()

bool icm20948::ICM20948_I2C::_read_mag_byte (

const uint8_t mag_reg,

uint8_t & byte) [private]

### 7.7.2.12 _set_accel_range_dlpf()

bool icm20948::ICM20948_I2C::_set_accel_range_dlpf () [private]

### 7.7.2.13 _set_accel_sample_rate_div()

bool icm20948::ICM20948_I2C::_set_accel_sample_rate_div () [private]

### 7.7.2.14 _set_bank()

bool icm20948::ICM20948_I2C::_set_bank (

uint8_t bank) [private]

### 7.7.2.15 _set_gyro_range_dlpf()

bool icm20948::ICM20948_I2C::_set_gyro_range_dlpf () [private]

### 38 Class Documentation

### 7.7.2.16 _set_gyro_sample_rate_div()

bool icm20948::ICM20948_I2C::_set_gyro_sample_rate_div () [private]

### 7.7.2.17 _write_bit()

bool icm20948::ICM20948_I2C::_write_bit (

const uint8_t bank,

const uint8_t reg,

const uint8_t bit_pos,

const bool bit) [private]

### 7.7.2.18 _write_byte()

bool icm20948::ICM20948_I2C::_write_byte (

const uint8_t bank,

const uint8_t reg,

const uint8_t byte) [private]

### 7.7.2.19 _write_mag_byte()

bool icm20948::ICM20948_I2C::_write_mag_byte (

const uint8_t mag_reg,

const uint8_t byte) [private]

### 7.7.2.20 check_DRDY_INT()

bool icm20948::ICM20948_I2C::check_DRDY_INT ()

Checks if the Data Ready Interrupt is active.

The function is run when the GPIO pin connected to the INT wire recieves a HIGH signal This reads the int_status register, reads the data from the data registers and thus unlatches the interrupt, ready for the next set of data

Returns

true if the registers were successfully read, false if an error occured

### 7.7.2.21 enable_DRDY_INT()

bool icm20948::ICM20948_I2C::enable_DRDY_INT ()

Enables the Data Ready Interrupt.

This function enables the Raw Data Ready Interrupt within the IMU by setting the specific registers so that it is notified when new data is available. When new data is available the INT pin on the IMU sends a HIGH value which can be read via a GPIO pin on the Pi.

Returns

true if the setup was successful, false if registers could not be written successefully

7.7 icm20948::ICM20948_I2C Class Reference | 39

### 7.7.3 Member Data Documentation

### 7.7.3.1 _accel_scale_factor

float icm20948::ICM20948_I2C::_accel_scale_factor [private]

### 7.7.3.2 _current_bank

uint8_t icm20948::ICM20948_I2C::_current_bank [private]

### 7.7.3.3 _gyro_scale_factor

float icm20948::ICM20948_I2C::_gyro_scale_factor [private]

### 7.7.3.4 _i2c

mraa::I2c icm20948::ICM20948_I2C::_i2c [private]

### 7.7.3.5 _i2c_address

unsigned icm20948::ICM20948_I2C::_i2c_address [private]

### 7.7.3.6 _i2c_bus

unsigned icm20948::ICM20948_I2C::_i2c_bus [private]

### 7.7.3.7 _magn_scale_factor

float icm20948::ICM20948_I2C::_magn_scale_factor [private]

### 7.7.3.8 accel

float icm20948::ICM20948_I2C::accel[3]

### 7.7.3.9 gyro

float icm20948::ICM20948_I2C::gyro[3]

### 7.7.3.10 magn

float icm20948::ICM20948_I2C::magn[3]

### 40 Class Documentation

### 7.7.3.11 settings

icm20948::settings icm20948::ICM20948_I2C::settings

The documentation for this class was generated from the following file:

- src/libs/I2C/include/icm20948_i2c.hpp

## 7.8 IMUMathsName::IMUMaths Class Reference

#include <IMUMaths.hpp>

Collaboration diagram for IMUMathsName::IMUMaths:

### IMUMathsName::IMUMaths + Pause + Counter - PlayFileCallback - LastFilePlayed + SoundChecker() + RegisterCallback()

### IMUMathsName::IMUMaths ::Callback

+ | AudioTrigger()
+ | ~Callback()
| -callback

Classes

- struct Callback

Empty callback to later be filled. Includes destructor.

Public Member Functions

- void SoundChecker (float X, float Y, float Z)

It measures each axis and sees if it falls within desired thresholds.
- void RegisterCallback (Callback ∗cb)

Registers a callback.

7.8 IMUMathsName::IMUMaths Class Reference | 41

Public Attributes

- bool Pause = false
- int Counter = 0

Private Attributes

- Callback ∗ callback = nullptr
- std::function< void(const std::string &)> PlayFileCallback
- int LastFilePlayed

### 7.8.1 Member Function Documentation

### 7.8.1.1 RegisterCallback()

void IMUMathsName::IMUMaths::RegisterCallback (

Callback ∗ cb) [inline]

Registers a callback.

Parameters

cb callback to register

### 7.8.1.2 SoundChecker()

void IMUMathsName::IMUMaths::SoundChecker (

float X,

float Y,

float Z)

It measures each axis and sees if it falls within desired thresholds.

If the acceleration along the specified axis falls within specified thersholds, it will play audio

Parameters

X | acceleration along the x-axis
Y | acceleration along the Y-axis
Z | acceleration along the Z-axis

### 7.8.2 Member Data Documentation

### 7.8.2.1 callback

Callback∗ IMUMathsName::IMUMaths::callback = nullptr [private]

### 42 Class Documentation

### 7.8.2.2 Counter

int IMUMathsName::IMUMaths::Counter = 0

### 7.8.2.3 LastFilePlayed

int IMUMathsName::IMUMaths::LastFilePlayed [private]

### 7.8.2.4 Pause

bool IMUMathsName::IMUMaths::Pause = false

### 7.8.2.5 PlayFileCallback

std::function<void(const std::string&)> IMUMathsName::IMUMaths::PlayFileCallback [private]

The documentation for this class was generated from the following file:

- src/libs/IMUMaths/include/IMUMaths.hpp

## 7.9 GPIOName::MathsCallbackStruct Struct Reference

#include <gpioevent.h>

Inheritance diagram for GPIOName::MathsCallbackStruct:

### GPIOName::MathsCallbackStruct

+ | Maths
+ | MathsCallbackStruct()
+ | MathsCallback()

### GPIOName::GPIOClass ::Callback

### + MathsCallback() + ~Callback()

7.9 GPIOName::MathsCallbackStruct Struct Reference | 43

Collaboration diagram for GPIOName::MathsCallbackStruct:

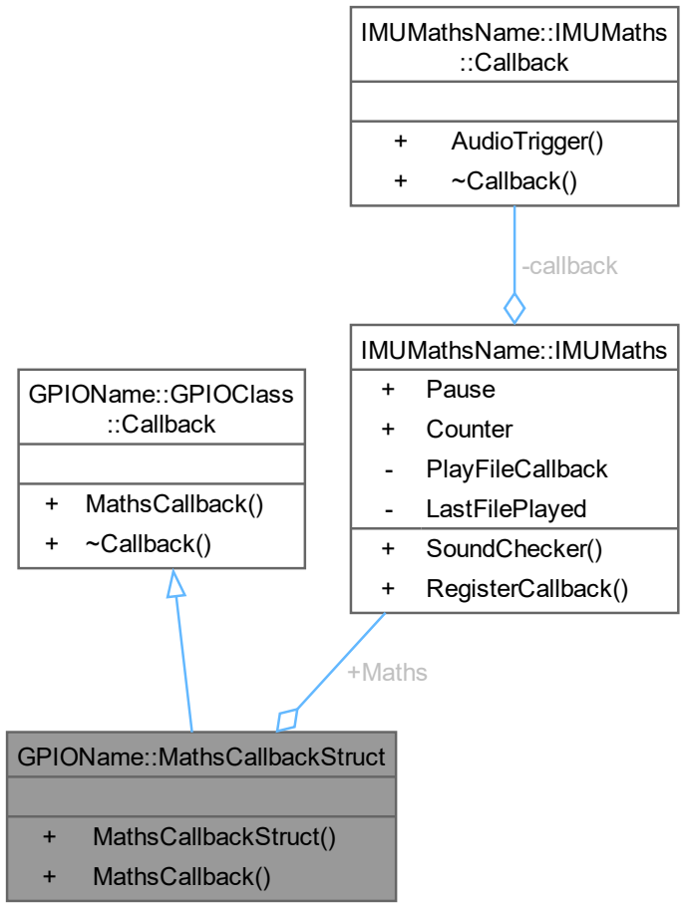
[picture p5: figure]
GPIOName::MathsCallbackStruct; MathsCallbackStruct(); MathsCallback(); GPIOName::GPIOClass ::Callback; + MathsCallback() + ~Callback(); IMUMathsName::IMUMaths + Pause + Counter - PlayFileCallback - LastFilePlayed + SoundChecker() + RegisterCallback(); +Maths; IMUMathsName::IMUMaths ::Callback; AudioTrigger(); ~Callback(); -callback

Public Member Functions

- MathsCallbackStruct (IMUMathsName::IMUMaths &maths)
- virtual void MathsCallback (float X, float Y, float Z) override

Public Member Functions inherited from GPIOName::GPIOClass::Callback

- virtual ∼Callback ()

Public Attributes

- IMUMathsName::IMUMaths & Maths

### 44 Class Documentation

### 7.9.1 Constructor & Destructor Documentation

### 7.9.1.1 MathsCallbackStruct()

GPIOName::MathsCallbackStruct::MathsCallbackStruct (

IMUMathsName::IMUMaths & maths) [inline]

### 7.9.2 Member Function Documentation

### 7.9.2.1 MathsCallback()

virtual void GPIOName::MathsCallbackStruct::MathsCallback (

float X,

float Y,

float Z) [inline], [override], [virtual]

Implements GPIOName::GPIOClass::Callback.

### 7.9.3 Member Data Documentation

### 7.9.3.1 Maths

IMUMathsName::IMUMaths& GPIOName::MathsCallbackStruct::Maths

The documentation for this struct was generated from the following file:

- src/libs/GPIO/include/gpioevent.h

# Chapter 8

# File Documentation

## 8.1 README.md File Reference

## 8.2 src/libs/ALSAPlayer/include/ALSAPlayer.hpp File Reference

#include <alsa/asoundlib.h> #include <string>

#include <vector>

#include <iostream>

#include <condition_variable> #include <mutex>

#include "AudioFile.h"

#include <unordered_map>

#include <thread>

Include dependency graph for ALSAPlayer.hpp:

src/libs/ALSAPlayer
/include/ALSAPlayer.hpp
alsa/asoundlib.h | string | vector | iostream | condition_variable | mutex | AudioFile.h | unordered_map | thread Generated by Doxygen

### 46 File Documentation

This graph shows which files directly or indirectly include this file:

### src/libs/ALSAPlayer /include/ALSAPlayer.hpp

### src/libs/IMUMaths/include /IMUMaths.hpp

### src/libs/GPIO/include /gpioevent.h

Classes

- class AudioPlayerName::AudioPlayer
- struct AudioPlayerName::AudioPlayer::ActiveSound

Namespaces

- namespace AudioPlayerName

## 8.3 ALSAPlayer.hpp

Go to the documentation of this file.

00001
00002 #ifndef ALSAPLAYER_H
00003 #define ALSAPLAYER_H
00004
00005 #include <alsa/asoundlib.h> 00006 #include <string>
00007 #include <vector>
00008 #include <iostream>
00009 #include <condition_variable> 00010 #include <mutex>
00011 #include "AudioFile.h"
00012 #include <unordered_map> 00013 #include <thread>
00014
00015
00016 namespace AudioPlayerName{
00017 | class AudioPlayer{
00018 | public:
00019 | std::unordered_map<std::string, std::vector<int32_t» fileBuffers;
00020
00021 | bool StopMixingThread = false;
00022
00035 | AudioPlayer(const std::string& device="default",
00036 | unsigned int rate = 44100,

8.3 ALSAPlayer.hpp | 47

unsigned int ch = 2,
snd_pcm_format_t fmt = SND_PCM_FORMAT_S16_LE, snd_pcm_uframes_t frames = 256,
const std::vector<std::string>& filesToConvert = {"src/libs/ALSAPlayer/include/CrashCymbal.wav",

"src/libs/ALSAPlayer/include/HighTom.wav",

"src/libs/ALSAPlayer/include/SnareDrum.wav"})
: deviceName(device), sampleRate(rate), channels(ch), format(fmt), framesPerPeriod(frames), handle(nullptr) {
if (!filesToConvert.empty()){ ConvertFiles(filesToConvert);
}
}

bool open(){
int rc = snd_pcm_open(&handle, deviceName.c_str(), SND_PCM_STREAM_PLAYBACK,0); if (rc < 0){
std::cerr « "Unable to open PCM devices: " « snd_strerror(rc) « std::endl; return false;
}

snd_pcm_hw_params_t* params;
snd_pcm_hw_params_alloca(&params);
snd_pcm_hw_params_any(handle, params);
snd_pcm_hw_params_set_access(handle, params, SND_PCM_ACCESS_RW_INTERLEAVED); snd_pcm_hw_params_set_format(handle, params, format); snd_pcm_hw_params_set_channels(handle, params, channels);

unsigned int rate_near = sampleRate;
snd_pcm_hw_params_set_rate_near(handle, params, &rate_near,0);

rc = snd_pcm_hw_params_set_period_size_near(handle, params, &framesPerPeriod, 0); if (rc <0) {
std::cerr « "Unable to set HW parameters: " « snd_strerror(rc) « std::endl; return false;
}
snd_pcm_uframes_t bufferSize = framesPerPeriod * 4;
rc = snd_pcm_hw_params_set_buffer_size_near(handle, params, &bufferSize);
if (rc < 0) {
std::cerr « "Unable to set buffer size: " « snd_strerror(rc) « std::endl; return false;
}

rc = snd_pcm_hw_params(handle, params);
if (rc < 0) {
std::cerr « "Unable to set HW parameters: " « snd_strerror(rc) « std::endl; return false;
}

// Verify the final chosen period size and buffer size snd_pcm_hw_params_get_period_size(params, &framesPerPeriod, 0); snd_pcm_hw_params_get_buffer_size(params, &bufferSize);
std::cout « "[DEBUG] Final period size: " « framesPerPeriod « std::endl; std::cout « "[DEBUG] Final buffer size: " « bufferSize « std::endl;

return true;
}

bool startMixer() {
if (!handle) {
std::cerr « "ALSA device is not open. Call open() first." « std::endl; return false;
}
StopMixingThread = false;
mixThread = std::thread(&AudioPlayer::mixerThreadLoop, this);

return true;
}

void stopMixer() {
StopMixingThread = true;
if (mixThread.joinable()) { mixThread.join();
}
}

bool addSoundToMixer(const std::string& fileKey) { std::lock_guard<std::mutex> lock(ActiveMutex);

// Check if file buffer exists
auto it = fileBuffers.find(fileKey);
if (it == fileBuffers.end()) {

### 48 File Documentation

std::cerr « "Audio buffer not found for file: " « fileKey « std::endl; return false;
}

// Create a new ActiveSound ActiveSound newSound;

// pointer to the file’s buffer newSound.buffer = &it->second; newSound.position = 0;

// Add it to active sounds ActiveSounds.push_back(newSound); return true;
}

void close() {
stopMixer();
if (handle) {
snd_pcm_drop(handle);
snd_pcm_close(handle);
handle = nullptr;
}
}

~AudioPlayer() {
close();
}

private:
std::string deviceName;
unsigned int sampleRate;
unsigned int channels;
snd_pcm_format_t format;
snd_pcm_uframes_t framesPerPeriod; snd_pcm_t* handle;

std::thread mixThread;

struct ActiveSound {
std::vector<int32_t>* buffer; size_t position;
};

std::vector<ActiveSound> ActiveSounds; std::mutex ActiveMutex;

void mixerThreadLoop() {
// Allocate a buffer for one period of audio
const size_t periodSizeSamples = framesPerPeriod * channels; std::vector<int32_t> mixBuffer(periodSizeSamples, 0);

while (!StopMixingThread) {
// Clear the mix buffer each iteration std::fill(mixBuffer.begin(), mixBuffer.end(), 0);

{
// Locks the active list ofsounds
std::lock_guard<std::mutex> lock(ActiveMutex);

// Mixes all of the activesounds and removes those that have finished for (auto it = ActiveSounds.begin(); it != ActiveSounds.end(); ) { ActiveSound& sound = *it;
const size_t totalFrames = sound.buffer->size() / channels; size_t framesLeft = totalFrames - sound.position;

// Callculate how may frakes are left to be mixed
size_t framesToMix = std::min<size_t>(framesPerPeriod, framesLeft);

//Mix the audio data from this sound into the buffer
for (size_t f = 0; f < framesToMix; ++f) {
for (unsigned int c = 0; c < channels; ++c) {
// Source index in the file buffer
size_t srcIndex = (sound.position + f) * channels + c; // Destination index in the mix buffer
size_t dstIndex = f * channels + c;

//Add up the sample
mixBuffer[dstIndex] += (*sound.buffer)[srcIndex]; }
}

// Advance playback position sound.position += framesToMix;

// If a sound has finished, remove it

8.4 src/libs/GPIO/include/gpioevent.h File Reference | 49

if (sound.position >= totalFrames) { it = ActiveSounds.erase(it);
} else {
++it;
}
}
}

// Write the mixed buffer to ALSA
int rc = snd_pcm_writei(handle, mixBuffer.data(), framesPerPeriod); if (rc == -EPIPE) {
std::cerr « "Underrun occurred\n";
snd_pcm_prepare(handle);
} else if (rc < 0) {
std::cerr « "Error from writei: " « snd_strerror(rc) « std::endl; }
}
}

void ConvertFiles(const std::vector<std::string>& filePaths) { std::vector<int32_t> result;

for (const auto& path : filePaths) {
AudioFile<int32_t> file;
if (!file.load(path)) {
std::cerr « "Error loading file: " « path « std::endl; continue;
}

int fileChannels = file.getNumChannels();
int ChannelSamples = file.getNumSamplesPerChannel();

std::vector<int32_t> interleaved; interleaved.reserve(ChannelSamples * fileChannels); for (int i=0; i < ChannelSamples; ++i){
for (int ch = 0; ch < fileChannels; ++ch){ interleaved.push_back(file.samples[ch][i]);

}

}
fileBuffers[path] = std::move(interleaved);

}
}

};
00299 }

00303 #endif

## 8.4 src/libs/GPIO/include/gpioevent.h File Reference

#include <gpiod.h>

#include <iostream>

#include <thread>

#include <chrono>

#include <iomanip>

#include <fstream>

#include <cstdint>

#include <functional>

#include <gtest/gtest.h>

#include "../../I2C/include/icm20948_i2c.hpp" #include "../../I2C/include/icm20948_utils.hpp" #include "../../IMUMaths/include/IMUMaths.hpp"

### 50 File Documentation

Include dependency graph for gpioevent.h:

Classes

- class GPIOName::GPIOClass
- struct GPIOName::GPIOClass::Callback

Empty callback to later be filled. Includes destructor.
- struct GPIOName::MathsCallbackStruct

Namespaces

- namespace GPIOName

## 8.5 gpioevent.h

Go to the documentation of this file.

00001 #ifndef GPIOEVENT_H
00002 #define GPIOEVENT_H
00003
00004
00005 #include <gpiod.h>
00006 #include <iostream>
00007 #include <thread>
00008 #include <chrono>
00009 #include <iomanip>
00010 #include <fstream>
00011 #include <cstdint>
00012 #include <functional>
00013 #include <gtest/gtest.h>
00014
00015 #include "../../I2C/include/icm20948_i2c.hpp" 00016 #include "../../I2C/include/icm20948_utils.hpp" 00017
00018 #include "../../IMUMaths/include/IMUMaths.hpp" 00019
00020
00021 namespace GPIOName {
00022 | class GPIOClass {
00023 | public:
00024
00033 | GPIOClass(const char* chipName, int InterruptPin,
00034 | icm20948::ICM20948_I2C& sensor);
00035
00044 | void Worker();
00045
00049 | void GPIOStop();
00050
00054 | struct Callback{
00055 | virtual void MathsCallback(float X, float Y, float Z) = 0;
00056 | virtual ~Callback(){};
00057 | };
00058
00066 | void RegisterCallback(Callback* cb){
00067 | callback = cb;
00068 | }
00069
00070 | //Testing private stuff

8.6 src/libs/I2C/include/icm20948_i2c.hpp File Reference | 51
00071 | #ifdef UNIT_TEST
00072 | bool GetRunning() const {
00073 | return running.load();
00074 | }
00075
00076 | bool HasCallback() const {
00077 | return callback != nullptr;
00078 | }
00079
00080 | Callback* GetCallback() const {
00081 | return callback;
00082 | }
00083
00084 | #endif
00085
00086 | private:
00087 | gpiod_chip* chip;
00088 | gpiod_line* SensorLine;
00089 | int InterruptPin;
00090 | int Counter;
00091 | bool Pause = true;
00092
00093 | //Reference to IMU’s driver
00094 | icm20948::ICM20948_I2C& sensor;
00095
00096 | std::atomic<bool> running{true};
00097 | Callback* callback = nullptr;
00098
00099 | };
00100
00101 | struct MathsCallbackStruct : GPIOName::GPIOClass::Callback{
00102 | IMUMathsName::IMUMaths& Maths;
00103
00104 | MathsCallbackStruct(IMUMathsName::IMUMaths& maths) : Maths(maths) {}
00105
00106 | virtual void MathsCallback(float X, float Y, float Z) override {
00107 | Maths.SoundChecker(X, Y, Z);
00108 | }
00109 | };
00110 }
00111
00112
00113
00114 #endif

## 8.6 src/libs/I2C/include/icm20948_i2c.hpp File Reference

#include <cstdint>

#include "mraa/common.hpp" #include "mraa/i2c.hpp"

#include "icm20948_defs.hpp" #include "icm20948_utils.hpp" Include dependency graph for icm20948_i2c.hpp:

src/libs/I2C/include
/icm20948_i2c.hpp
cstdint | mraa/common.hpp | mraa/i2c.hpp | icm20948_defs.hpp | icm20948_utils.hpp Generated by Doxygen

### 52 File Documentation

This graph shows which files directly or indirectly include this file:

### src/libs/I2C/include /icm20948_i2c.hpp

### src/libs/GPIO/include /gpioevent.h

Classes

- class icm20948::ICM20948_I2C

Namespaces

- namespace icm20948

## 8.7 icm20948_i2c.hpp

Go to the documentation of this file.

00001 #ifndef ICM20948_I2C_HPP 00002 #define ICM20948_I2C_HPP 00003
00004 #include <cstdint>
00005
00006 #include "mraa/common.hpp" 00007 #include "mraa/i2c.hpp" 00008
00009 #include "icm20948_defs.hpp" 00010 #include "icm20948_utils.hpp" 00011
00012 namespace icm20948
00013 {
00014 | class ICM20948_I2C
00015 | {
00016 | private:
00017 | mraa::I2c _i2c;
00018 | unsigned _i2c_bus, _i2c_address;
00019 | uint8_t _current_bank;
00020 | float _accel_scale_factor, _gyro_scale_factor, _magn_scale_factor;
00021
00022 | bool _write_byte(const uint8_t bank, const uint8_t reg, const uint8_t byte);
00023 | bool _read_byte(const uint8_t bank, const uint8_t reg, uint8_t &byte);
00024 | bool _write_bit(const uint8_t bank, const uint8_t reg, const uint8_t bit_pos, const bool
| bit);
00025 | bool _read_bit(const uint8_t bank, const uint8_t reg, const uint8_t bit_pos, bool &bit);
00026 | bool _read_block_bytes(const uint8_t bank, const uint8_t start_reg, uint8_t *bytes, const
| int length);
00027 | bool _write_mag_byte(const uint8_t mag_reg, const uint8_t byte);
00028 | bool _read_mag_byte(const uint8_t mag_reg, uint8_t &byte);
00029 | bool _read_int_byte(const uint8_t bank, const uint8_t reg, uint8_t &byte);
00030
00031 | bool _set_bank(uint8_t bank);
00032 | bool _set_accel_sample_rate_div();
00033 | bool _set_accel_range_dlpf();

8.8 src/libs/IMUMaths/include/IMUMaths.hpp File Reference | 53
00034 | bool _set_gyro_sample_rate_div();
00035 | bool _set_gyro_range_dlpf();
00036
00037 | bool _magnetometer_init();
00038 | bool _magnetometer_enable();
00039 | bool _magnetometer_set_mode();
00040 | bool _magnetometer_configured();
00041 | bool _magnetometer_set_readout();
00042
00043 | bool _chip_i2c_master_reset();
00044
00045 | public:
00046 | // Contains linear acceleration in m/s^2
00047 | float accel[3];
00048 | // Contains angular velocities in rad/s
00049 | float gyro[3];
00050 | // Contains magnetic field strength in uTesla
00051 | float magn[3];
00052
00053 | // Sensor settings
00054 | icm20948::settings settings;
00055
00065 | ICM20948_I2C(unsigned i2c_bus, unsigned i2c_address = ICM20948_I2C_ADDR,
| icm20948::settings
00066 | = icm20948::settings());
00067
00069
00085 | bool init();
00086
00100 | bool reset();
00101
00112 | bool wake();
00113
00129 | bool set_settings();
00130
00144 | bool read_accel_gyro();
00145
00157 | bool read_magn();
00158
00160
00171 | bool enable_DRDY_INT();
00172
00182 | bool check_DRDY_INT();
00183 | };
00184 }
00185
00186 #endif

## 8.8 src/libs/IMUMaths/include/IMUMaths.hpp File Reference

#include <iostream>

#include <array>

#include <iomanip>

#include <functional>

#include "../../ALSAPlayer/include/ALSAPlayer.hpp" Include dependency graph for IMUMaths.hpp:

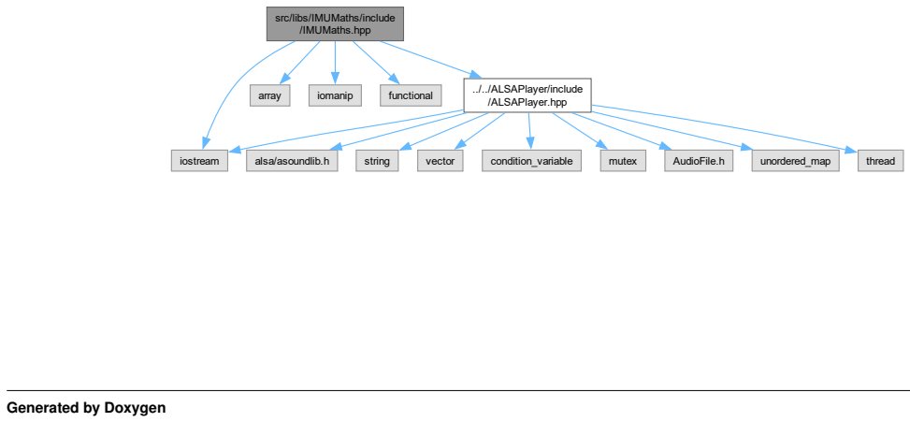
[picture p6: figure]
src/libs/IMUMaths/include /IMUMaths.hpp; iostream; array; iomanip; functional; ../../ALSAPlayer/include; /ALSAPlayer.hpp; alsa/asoundlib.h; string; vector; condition_variable; mutex; AudioFile.h; unordered_map; thread Generated by Doxygen

### 54 File Documentation

This graph shows which files directly or indirectly include this file:

### src/libs/IMUMaths/include /IMUMaths.hpp

### src/libs/GPIO/include /gpioevent.h

Classes

- class IMUMathsName::IMUMaths
- struct IMUMathsName::IMUMaths::Callback

Empty callback to later be filled. Includes destructor.
- struct IMUMathsName::AudioCallback

Namespaces

- namespace IMUMathsName

## 8.9 IMUMaths.hpp

Go to the documentation of this file.

00001 #ifndef IMUMATHS_H
00002 #define IMUMATHS_H
00003
00004
00005 #include <iostream>
00006 #include <array>
00007 #include <iomanip>
00008 #include <functional>
00009
00010 #include "../../ALSAPlayer/include/ALSAPlayer.hpp" 00011
00012
00013 namespace IMUMathsName {
00014 | class IMUMaths{
00015
00016 | public:
00017
00028 | void SoundChecker(float X, float Y, float Z);
00029
00030 | // Pauses
00031 | bool Pause = false;
00032
00033 | // Counter variable
00034 | int Counter = 0;
00035
00039 | struct Callback{
00040 | virtual void AudioTrigger(const std::string& FilePath) = 0;
00041 | virtual ~Callback(){};
00042 | };

8.9 IMUMaths.hpp | 55

void RegisterCallback(Callback* cb){
callback = cb;
//std::cout « "[IMUMaths] Registered callback at address: " « callback « std::endl; }

//Access to private fo UNIT_TEST only
#ifdef UNIT_TEST

bool HasCallback() const {
return callback != nullptr; }

Callback* GetCallback() const { return callback;
}

int LastFilePlayedTest() const{ return LastFilePlayed;
}

#endif

private:

Callback* callback = nullptr;
std::function<void(const std::string&)> PlayFileCallback;

// For debugging: Identifier of the last audio file played

int LastFilePlayed;

};

struct AudioCallback : IMUMathsName::IMUMaths::Callback{ AudioPlayerName::AudioPlayer& Audio;

AudioCallback(AudioPlayerName::AudioPlayer& audio) : Audio(audio) {}

virtual void AudioTrigger(const std::string& FilePath){ std::thread([this,FilePath]{
Audio.addSoundToMixer(FilePath);

}).detach();
}
};
00097 }

00100 #endif

### 56 File Documentation

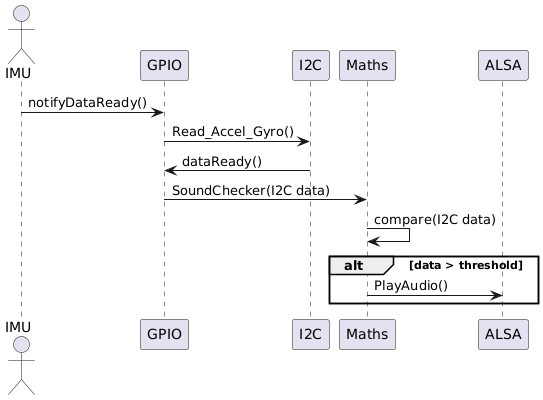
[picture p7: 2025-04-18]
UML/UML_diagram_simple.png

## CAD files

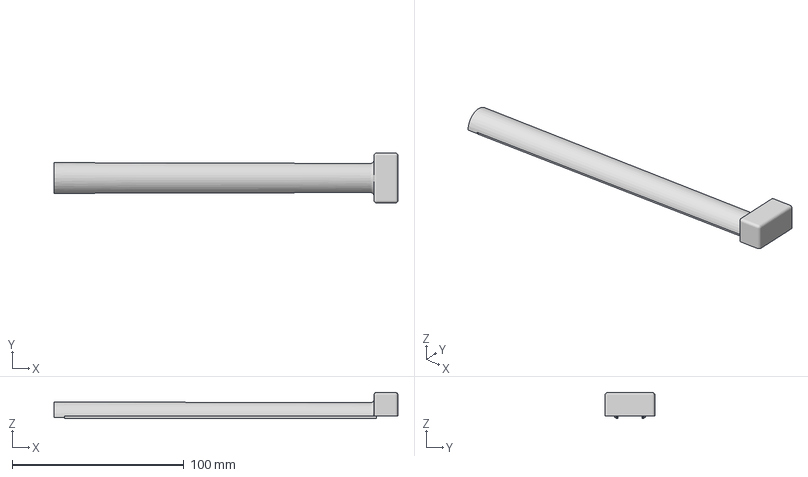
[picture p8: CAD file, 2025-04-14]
STL/Top_Tip.3mf
200.2 x 29.0 x 15.2 mm

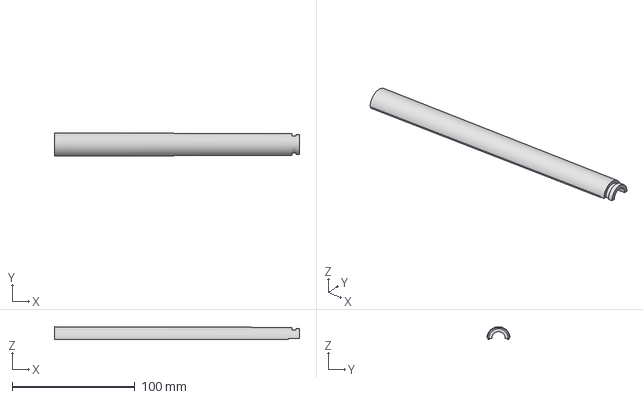
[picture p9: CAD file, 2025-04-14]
STL/Top_Base.3mf
199.8 x 18.8 x 10.2 mm

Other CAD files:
STL/Bottom_Base.3mf
STL/Bottom_Tip.3mf
STL/Bottom_Base.stl
STL/Bottom_Tip.stl
STL/Top_Base.stl
STL/Top_Tip.stl

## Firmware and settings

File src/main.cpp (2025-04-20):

#include "libs/I2C/include/icm20948_i2c.hpp"
#include "libs/I2C/include/icm20948_defs.hpp"

#include "libs/GPIO/include/gpioevent.h"
#include "libs/IMUMaths/include/IMUMaths.hpp"
#include "libs/ALSAPlayer/include/ALSAPlayer.hpp"

#include <iostream> 
#include <gpiod.h>
#include <thread>
#include <string>



//Driver objects for the IMUs
//Using difference I2C addresses allows them to run on the same I2C bus
icm20948::ICM20948_I2C objI2C(1,0x69); 
icm20948::ICM20948_I2C objI2C_2(1,0x68); 

//Object for ALSA Audio Player
AudioPlayerName::AudioPlayer objALSA("plughw:CARD=UACDemoV10,DEV=0", 44100, 2, SND_PCM_FORMAT_S16_LE, 128);

//Object for Maths operations
IMUMathsName::IMUMaths objMaths;

//Object for GPIO operations
//17 and 27 refer to GPIO pins on the raspberry pi (11 and 13)
//Require access the IMU's I2C driver for access to registers
GPIOName::GPIOClass objGPIO("gpiochip0", 17, objI2C);
GPIOName::GPIOClass objGPIO_2("gpiochip0",27, objI2C_2);


//All initialisation for SnairBeats
bool InitSnairBeat(){

    //Sample rate is divided by these values
    //1.125kHz / (1 + sample_rate_div)

    int SampleRateDivider = 44;
    // 1125/(44 + 1) = 25Hz

    objI2C.settings.accel.sample_rate_div = SampleRateDivider;
    objI2C.settings.gyro.sample_rate_div = SampleRateDivider;
    objI2C.settings.accel.scale = icm20948::ACCEL_16G;
    objI2C.settings.gyro.scale = icm20948::GYRO_2000DPS;

    objI2C_2.settings.accel.sample_rate_div = SampleRateDivider;
    objI2C_2.settings.gyro.sample_rate_div = SampleRateDivider;
    objI2C_2.settings.accel.scale = icm20948::ACCEL_16G;
    objI2C_2.settings.gyro.scale = icm20948::GYRO_2000DPS;
    
    std::cout << "Object 1 created!\n";
    if(objI2C.init())
    {

        if (objI2C.enable_DRDY_INT()){
            std::cout << "Data Ready Interrupt enabled in Object 1" << std::endl;
        } else {
            std::cerr <<"Failed to enable DRDY interrupt" << std::endl;
        }
    } else {
        std::cout << "Womp Womp - No worky in Object 1" << std::endl;
        return -1;
    }

    std::cout << "Object 2 created!\n";
    if(objI2C_2.init())
    {
        if (objI2C_2.enable_DRDY_INT()){
            std::cout << "Data Ready Interrupt enabled in Object 2" << std::endl;
        } else {
            std::cerr <<"Failed to enable DRDY interrupt" << std::endl;
        }
    } else {
        std::cout << "Womp Womp - No worky in Object 2" << std::endl;
        return -1;
    }

    if (!objALSA.open()) {
        std::cerr << "[ALSAPlayer] Warning: Failed to open ALSA device.\n";
    }

    if (!objALSA.startMixer()){
        std::cerr << "[ALSAPlayer] Warning: Failed to start mixing thread\n";

    }

    return 1;
}



int main() {

    bool success = true;

    success &= InitSnairBeat();
    if (!success){
        std::cerr << "Something failed in initialisation - go fix it" << std::endl;
        return -1;
    }
    


    //Register callback for Audio
    IMUMathsName::AudioCallback Audio_Callback(objALSA);
    objMaths.RegisterCallback(&Audio_Callback);

    //Register callback for Maths in the GPIO objects
    GPIOName::MathsCallbackStruct Maths_Callback(objMaths);
    objGPIO.RegisterCallback(&Maths_Callback);
    objGPIO_2.RegisterCallback(&Maths_Callback);
    

    //Thread for IMU workers 
    std::thread gpioThread(&GPIOName::GPIOClass::Worker, &objGPIO);
    std::thread gpioThread_2(&GPIOName::GPIOClass::Worker, &objGPIO_2);
    
    //Close down the program after Enter is pressed
    std::cout << "Press Enter to stop SnairBeats" << std::endl;
    getchar();

    //Swaps running atomic boolean in GPIO objects to false
    //Stopping them next iteration
    objGPIO.GPIOStop();
    objGPIO_2.GPIOStop();
            
    if(gpioThread.joinable()){
        gpioThread.join();
        }

    if(gpioThread_2.joinable()){
        gpioThread_2.join();
        }

    objALSA.stopMixer();
    objALSA.close();
    
    std::cout << "Everything closed.\nExiting SnairBeat" << std::endl;

    return 0;

}

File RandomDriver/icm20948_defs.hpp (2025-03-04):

#ifndef ICM20948_REGS_HPP
#define ICM20948_REGS_HPP

// Generic defines
#define ICM20948_I2C_ADDR       0x69
#define ICM20948_MAGN_I2C_ADDR  0x0C

// Banks
// Bank 0
#define ICM20948_WHO_AM_I_BANK              0

#define ICM20948_USER_CTRL_BANK             0

#define ICM20948_PWR_MGMT_1_BANK            0

#define ICM20948_INT_PIN_CFG_BANK           0

#define ICM20948_I2C_MST_STATUS_BANK        0

#define ICM20948_ACCEL_OUT_BANK             0
#define ICM20948_GYRO_OUT_BANK              0
#define ICM20948_TEMP_OUT_BANK              0
#define ICM20948_EXT_SLV_SENS_DATA_00_BANK  0

// Bank 2
#define ICM20948_GYRO_SMPLRT_DIV_BANK       2
#define ICM20948_GYRO_CONFIG_1_BANK         2
#define ICM20948_ACCEL_SMPLRT_DIV_1_BANK    2
#define ICM20948_ACCEL_SMPLRT_DIV_2_BANK    2
#define ICM20948_ACCEL_CONFIG_1_BANK        2

// Bank 3
#define ICM20948_I2C_MST_CTRL_BANK          3
#define ICM20948_I2C_SLV0_ADDR_BANK         3
#define ICM20948_I2C_SLV0_REG_BANK          3
#define ICM20948_I2C_SLV0_CTRL_BANK         3
#define ICM20948_I2C_SLV4_ADDR_BANK         3
#define ICM20948_I2C_SLV4_REG_BANK          3
#define ICM20948_I2C_SLV4_CTRL_BANK         3
#define ICM20948_I2C_SLV4_DO_BANK           3
#define ICM20948_I2C_SLV4_DI_BANK           3



// Addresses
#define ICM20948_REG_BANK_SEL_ADDR          0x7F

// Addresses: Bank 0
#define ICM20948_WHO_AM_I_ADDR              0x00

#define ICM20948_USER_CTRL_ADDR             0x03

#define ICM20948_PWR_MGMT_1_ADDR            0x06

#define ICM20948_INT_PIN_CFG_ADDR           0x0F

#define ICM20948_I2C_MST_STATUS_ADDR        0x17

#define ICM20948_ACCEL_XOUT_H_ADDR          0x2D
#define ICM20948_ACCEL_XOUT_L_ADDR          0x2E
#define ICM20948_ACCEL_YOUT_H_ADDR          0x2F
#define ICM20948_ACCEL_YOUT_L_ADDR          0x30
#define ICM20948_ACCEL_ZOUT_H_ADDR          0x31
#define ICM20948_ACCEL_ZOUT_L_ADDR          0x32

#define ICM20948_GYRO_XOUT_H_ADDR           0x33
#define ICM20948_GYRO_XOUT_L_ADDR           0x34
#define ICM20948_GYRO_YOUT_H_ADDR           0x35
#define ICM20948_GYRO_YOUT_L_ADDR           0x36
#define ICM20948_GYRO_ZOUT_H_ADDR           0x37
#define ICM20948_GYRO_ZOUT_L_ADDR           0x38

#define ICM20948_TEMP_OUT_H_ADDR            0x39
#define ICM20948_TEMP_OUT_L_ADDR            0x3A

#define ICM20948_EXT_SLV_SENS_DATA_00_ADDR  0x3B

// Addresses: Bank 2
#define ICM20948_GYRO_SMPLRT_DIV_ADDR       0x00
#define ICM20948_GYRO_CONFIG_1_ADDR         0x01
#define ICM20948_ACCEL_SMPLRT_DIV_1_ADDR    0x10
#define ICM20948_ACCEL_SMPLRT_DIV_2_ADDR    0x11
#define ICM20948_ACCEL_CONFIG_1_ADDR        0x14

// Addresses: Bank 3
#define ICM20948_I2C_MST_CTRL_ADDR          0x01
#define ICM20948_I2C_SLV0_ADDR_ADDR         0x03
#define ICM20948_I2C_SLV0_REG_ADDR          0x04
#define ICM20948_I2C_SLV0_CTRL_ADDR         0x05
#define ICM20948_I2C_SLV4_ADDR_ADDR         0x13
#define ICM20948_I2C_SLV4_REG_ADDR          0x14
#define ICM20948_I2C_SLV4_CTRL_ADDR         0x15
#define ICM20948_I2C_SLV4_DO_ADDR           0x16
#define ICM20948_I2C_SLV4_DI_ADDR           0x17



// Values
#define ICM20948_REG_BANK_SEL_BANK0_VALUE 0x00
#define ICM20948_REG_BANK_SEL_BANK1_VALUE 0x10
#define ICM20948_REG_BANK_SEL_BANK2_VALUE 0x20
#define ICM20948_REG_BANK_SEL_BANK3_VALUE 0x30

// Values: Bank 0
#define ICM20948_BANK0_WHO_AM_I_VALUE     0xEA



// Magnetometer (AK09916)
#define AK09916_CNTL2_ADDR  0x31

#endif

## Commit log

2025-03-04 Initial IMU driver + random tests
2025-03-05 Interrupt file for IMU
2025-03-12 Wake on Motion Interrupt
2025-03-17 Blocking Interrupt
2025-04-02 Audio driver - BUG:No sound from speaker
    [main.cpp]
2025-04-03 Fixed sample rate and DRDY Interrupts
    [main.cpp]
2025-04-10 Rollback before camera addition
2025-04-11 C++ playing Audio and interrupts
2025-04-13 Create ignore.txt
    To create the FIGURES folder cause VS code can't see it and Im getting tired
2025-04-13 Wiring Guide
    PNG of the wiring guide
2025-04-13 Thread to close objects
2025-04-13 updated keyboard interrupt
2025-04-14 Add files via upload
    Files to print the parts of the drum stick in .stl and .3mf format.
    [Bottom_Base.3mf, Bottom_Base.stl, Bottom_Tip.3mf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]
2025-04-14 Parallel IMU - Requires Testing
2025-04-15 Second IMU added
2025-04-15 Added comments to i2c hpp files and IMUMaths hpp file
2025-04-16 Unit Tests -GPIO -IMUMaths
2025-04-17 AD0 in Wiring Guide Image
2025-04-20 Cloased ALSA device
